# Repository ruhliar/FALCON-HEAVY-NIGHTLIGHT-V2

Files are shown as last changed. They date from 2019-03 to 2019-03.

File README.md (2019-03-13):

# FALCON-HEAVY-NIGHTLIGHT-V2
Files for you to create an awesome 3D printed Falcon Heavy Nightlight

This thing can be found on Thingiverse.com www.thingiverse.com/thing:3066586
This project is using a file from https://www.thingiverse.com/thing:456900
I scaled all models up 200%, added magnets and 2x 18650 battery + charge, protect, boost. I programmed Arduino Nano so you can chose from 3 main LED programs or the same, with stronger light. 
Print rocket at 100% infill
Exhaust at 0% infill with 3 perimeters

BOM:
https://www.ebay.com/itm/10PCS-Lot-2-Pin-12V-Car-Boat-Round-Dot-Light-ON-OFF-Rocker-Toggle-Switch-Tool/391842691497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

https://www.ebay.com/itm/1W-3W-High-Power-cool-warm-white-3000k-4000k-10000k-30000k-LED-20mm-star-pcb/321471559197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

https://www.ebay.com/itm/2-5-10PCS-TP4056-5V-1A-USB-18650-Lithium-Battery-Charger-Board-Protection-Module/132530522140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

https://www.ebay.com/itm/1-2-4-6-8-10-12-16X-18650-Batterie-9800mAh-Li-ion-rechargeable-Battery-Flat-top/142882388958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

https://www.ebay.com/itm/DC-Micro-USB-2-24V-To-5-28V-Boost-Step-Up-Regulator-Power-Module-2A-Adjustable/292462870496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

https://www.ebay.com/itm/1PCS-mini-USB-Nano-V3-0-ATmega328P-CH340G-5V-16M-micro-controller-Arduino/191773759569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

https://www.ebay.com/itm/50PCS-S8050-S8050D-8050-TRANSISTOR-NPN-25V-1-5A-TO-92-FSC-S/191880503222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

https://www.ebay.com/itm/10PCS-Double-Side-Prototype-PCB-Bread-board-Tinned-Universal-FR4-2x8cm-9x15cm/201677782881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

After printing the rocket I drilled 9mm holes to rocket's bottom so I was able to insert and glue 2 of 8x3mm round magnets inside. 
After all that was done I used various sandpapers, spray filler and white spray to hide all the magnets and layers. 
Next, I've glued magnets with matching pole of magnets on the rocket to exhaust with superglue. 
I tested all the electronics and code on breadboard and after that was done, I soldered everything on piece of prototyping perfboard. 
I set up the battery pack with cheap modules that provided charge protect and boost functions and after testing everything together I noticed that the step-up module was making some quiet, weird sound. 
I tied adding a 100uF 50v capacitor to its output and the noise magically disappeared.
Now I have a very good looking model of Falcon Heavy rocket lighting my room at night.

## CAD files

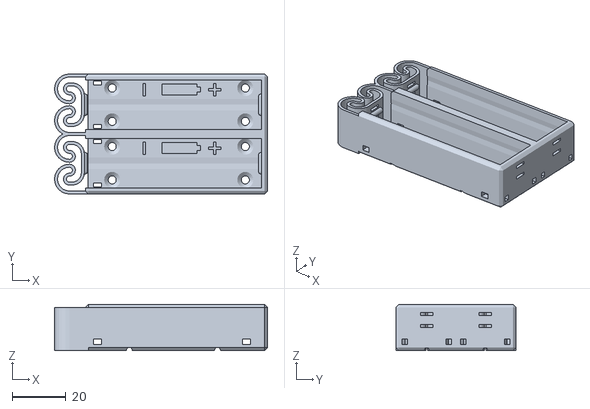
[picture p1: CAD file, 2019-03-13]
flexbatter18650x2.stl
79.2 x 44.6 x 17.2

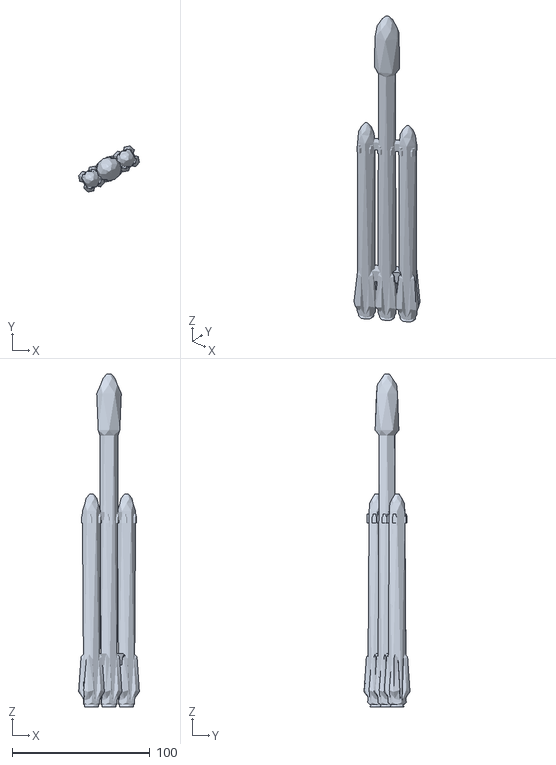
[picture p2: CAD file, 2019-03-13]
Falcon Heavy Nightlight V2_Rocket.stl
44.1 x 33.4 x 241.4

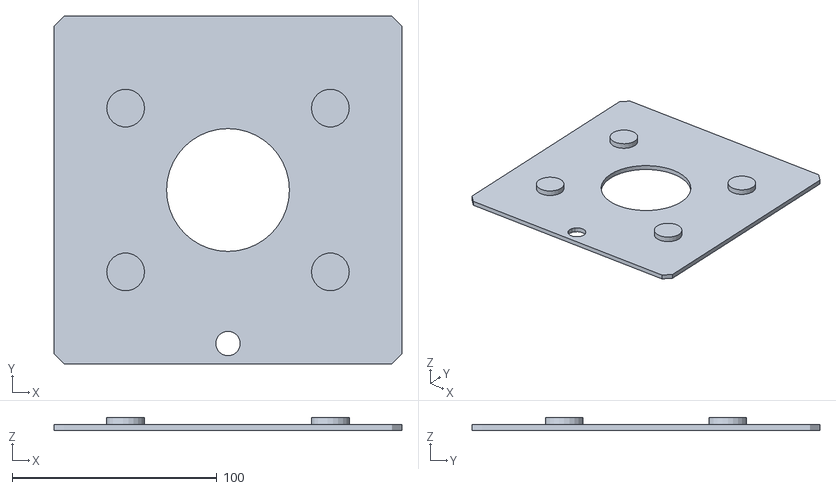
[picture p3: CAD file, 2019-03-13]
Falcon Heavy Nightlight V2_Base1.stl
170.0 x 170.0 x 6.50

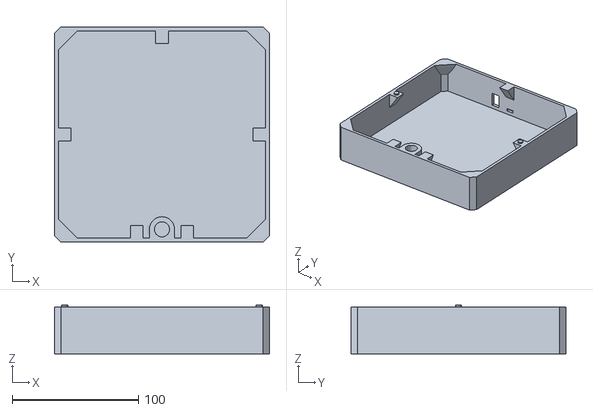
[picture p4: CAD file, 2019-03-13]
Falcon Heavy Nightlight V2_Base2.stl
170.0 x 170.0 x 38.4

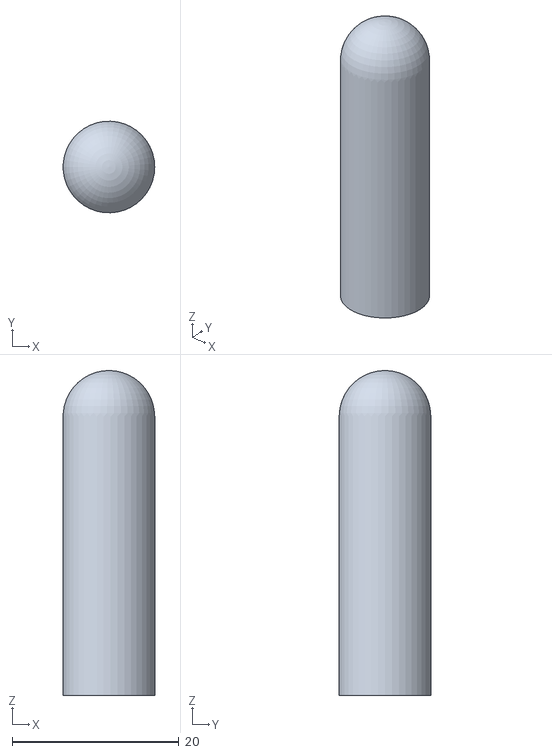
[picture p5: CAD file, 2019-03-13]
Falcon Heavy Nightlight V2_Base3.stl
11.0 x 11.0 x 39.0

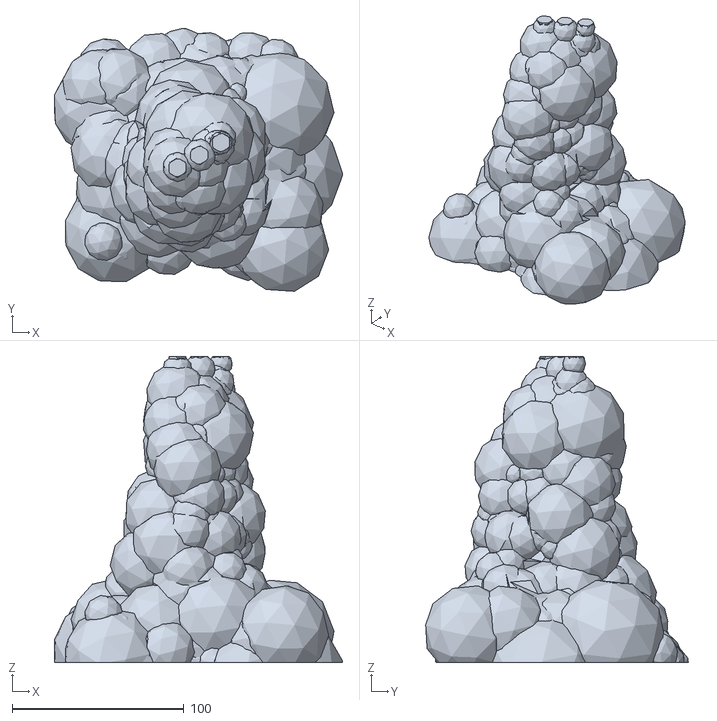
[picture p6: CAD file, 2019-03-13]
Falcon Heavy Nightlight V2_Exhaust.stl
167.8 x 152.8 x 178.0

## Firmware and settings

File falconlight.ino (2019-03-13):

int led = 9;           // the PWM pin the LED is attached to
int buttonState;
int brightness1 = 0;    // how bright the LED is
int fadeAmount1 = 5;    // how many points to fade the LED by
int brightness2 = 0;    // how bright the LED is
int fadeAmount2 = 3;    // how many points to fade the LED by
void setup() {
  pinMode(led, OUTPUT);
  pinMode(2, INPUT);
  flicker();
}

void loop() {
}
void flicker() {
  analogWrite(led, random(30) + 40);
  delay(random(100));
  buttonState = digitalRead(2);
  if (buttonState == HIGH) {
    delay(150);
    strongFlicker();
  }
  else {
    flicker();
  }
}
void strongFlicker() {
  analogWrite(led, random(120) + 130);
  delay(random(100));
  buttonState = digitalRead(2);
  if (buttonState == HIGH) {
    delay(150);
    light();
  }
  else {
    strongFlicker();
  }
}
void light() {
  analogWrite(led, 80);
  delay(100);
  buttonState = digitalRead(2);
  if (buttonState == HIGH) {
    delay(150);
    strongLight();
  }
  else {
    light();
  }
}
void strongLight() {
  analogWrite(led, 140);
  delay(100);
  buttonState = digitalRead(2);
  if (buttonState == HIGH) {
    delay(150);
    fade();
  }
  else {
    strongLight();
  }
}
void fade() {
  analogWrite(led, brightness1);
  brightness1 = brightness1 + fadeAmount1;
  if (brightness1 <= 0 || brightness1 >= 255) {
    fadeAmount1 = -fadeAmount1;
  }
  delay(30);
  buttonState = digitalRead(2);
  if (buttonState == HIGH) {
    delay(150);
    strongFade();
  }
  else {
    fade();
  }
}
void strongFade() {
  analogWrite(led, brightness2);
  brightness2 = brightness2 + fadeAmount2;
  if (brightness2 <= 0 || brightness2 >= 255) {
    fadeAmount2 = -fadeAmount2;
  }
  delay(10);
  buttonState = digitalRead(2);
  if (buttonState == HIGH) {
    delay(150);
    flicker();
  }
  else {
    strongFade();
  }
}
